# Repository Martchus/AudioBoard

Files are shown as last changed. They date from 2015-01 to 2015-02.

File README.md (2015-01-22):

# AudioBoard

Im Ordner Hardware befindet sich der Schaltplan als KiCAD Projekt und die Gerberdaten der Platine.

Die Software gibt es als "Basic" Version, welche die Grundlegenden Funktionen zur verfügung stellt. Auf der Basis von diesen Daten können eigene Projekte entwickelt werden.
Der Quelltext zum Matrixprojekt ist auf genau dieses Projekt zugeschnitten. Es wird dazu eine 7x6 Matrix mit WS2812 LEDs erwartete, welche alle seriell verbunden sind. Dieser Quelltext soll eher als Inspiration dienen.

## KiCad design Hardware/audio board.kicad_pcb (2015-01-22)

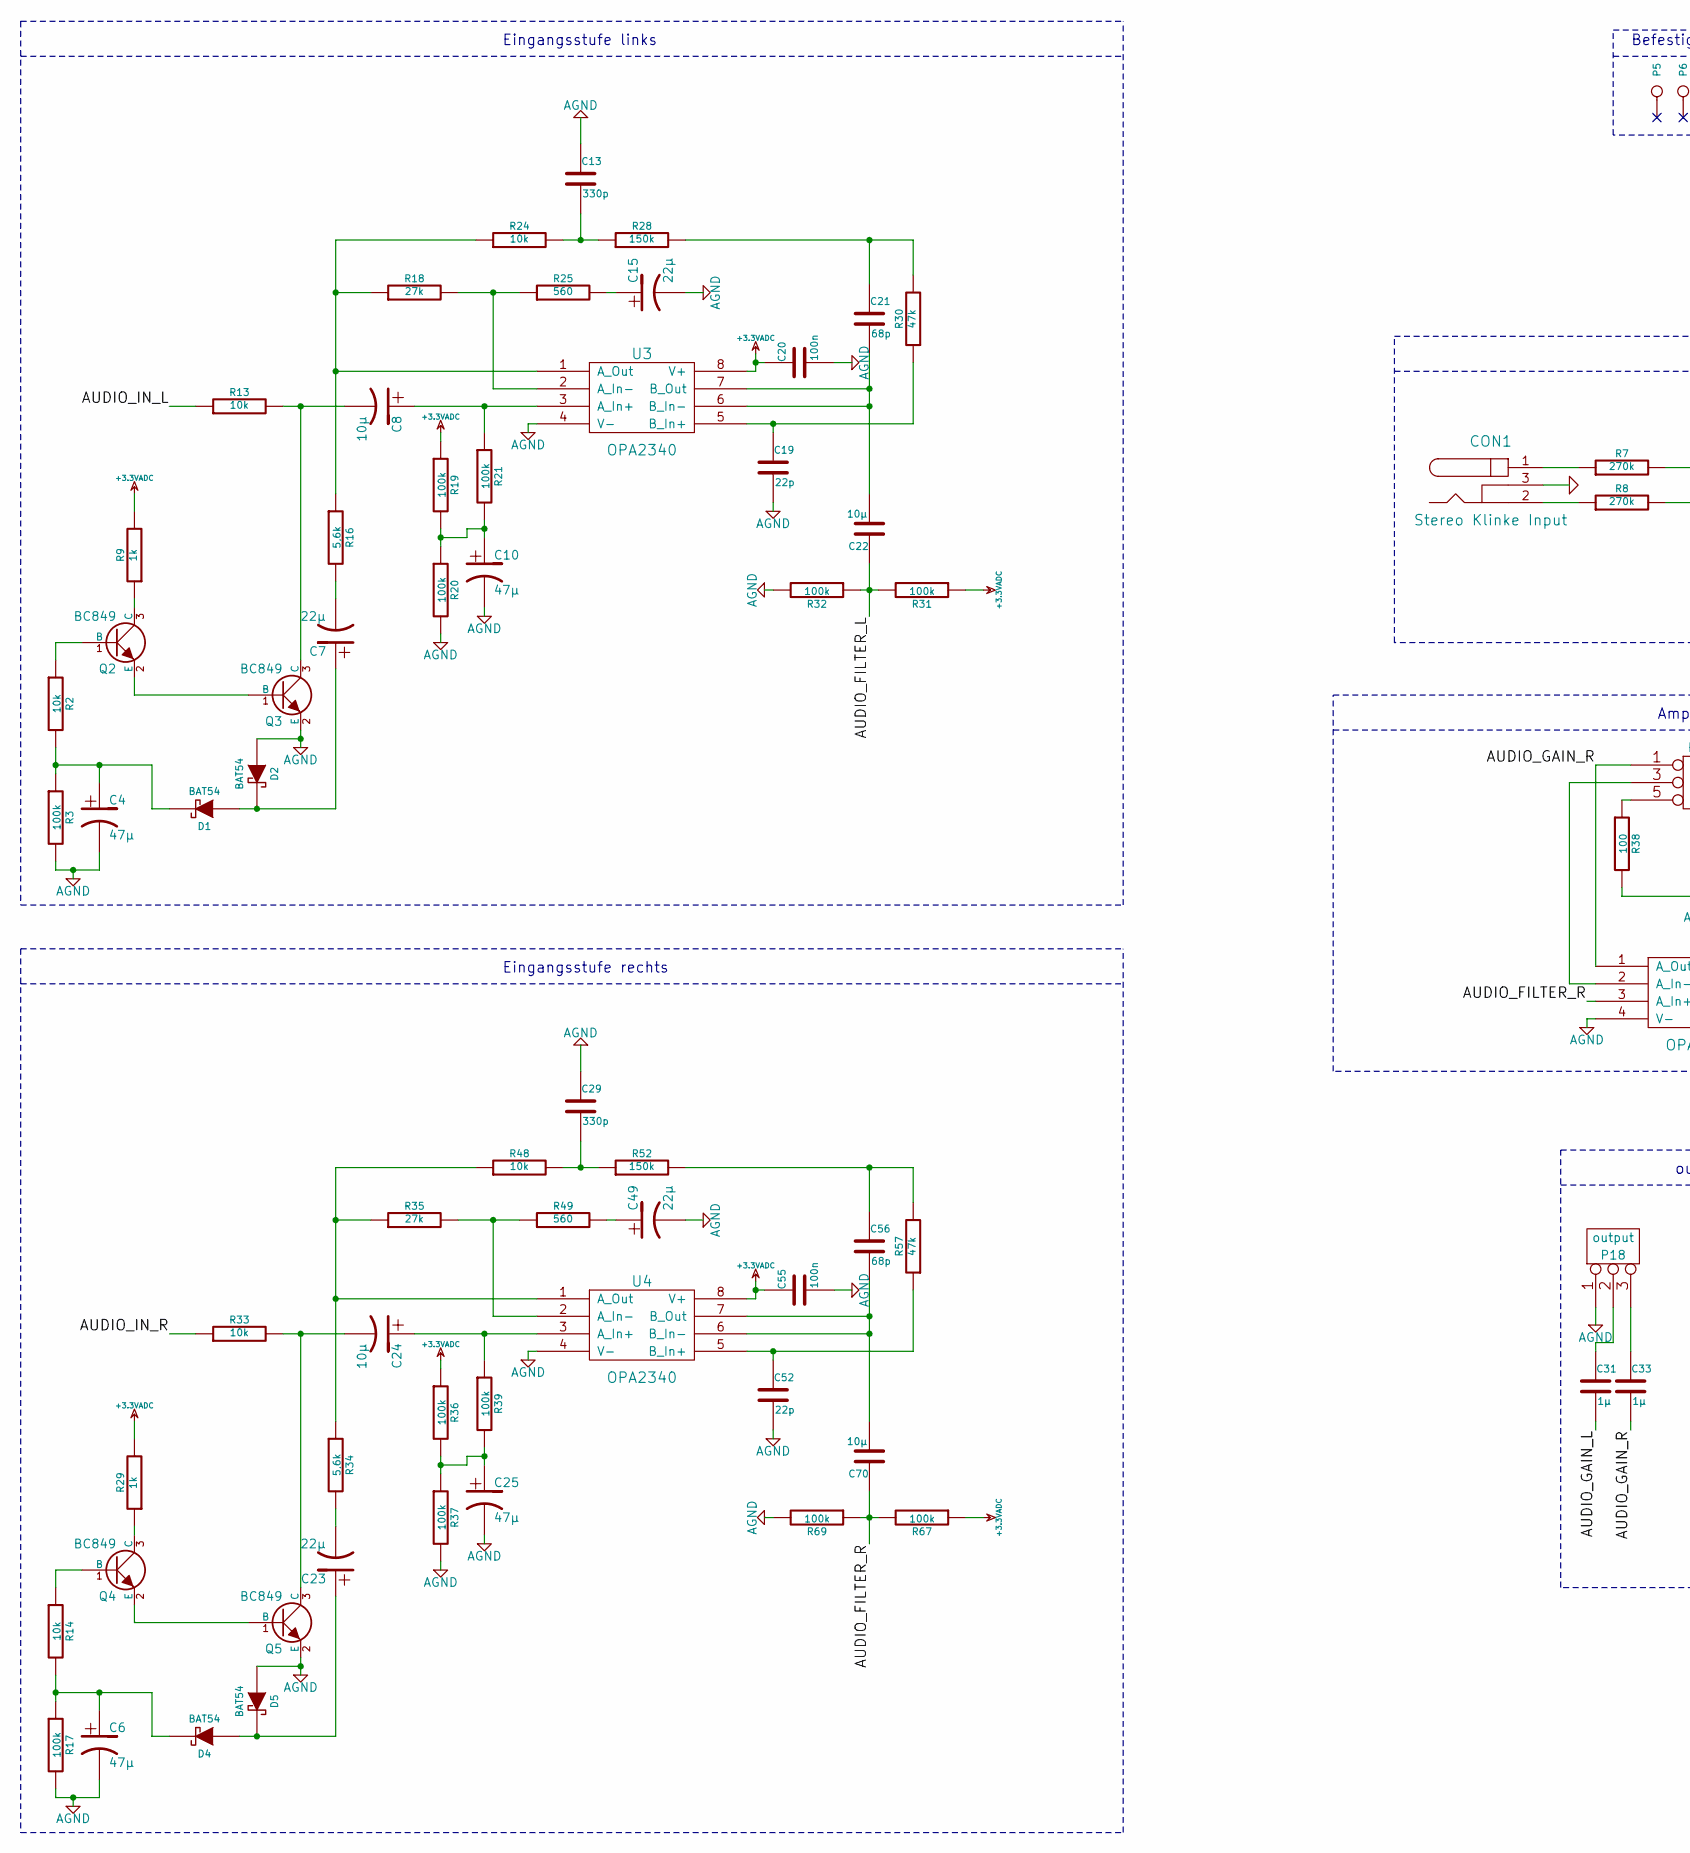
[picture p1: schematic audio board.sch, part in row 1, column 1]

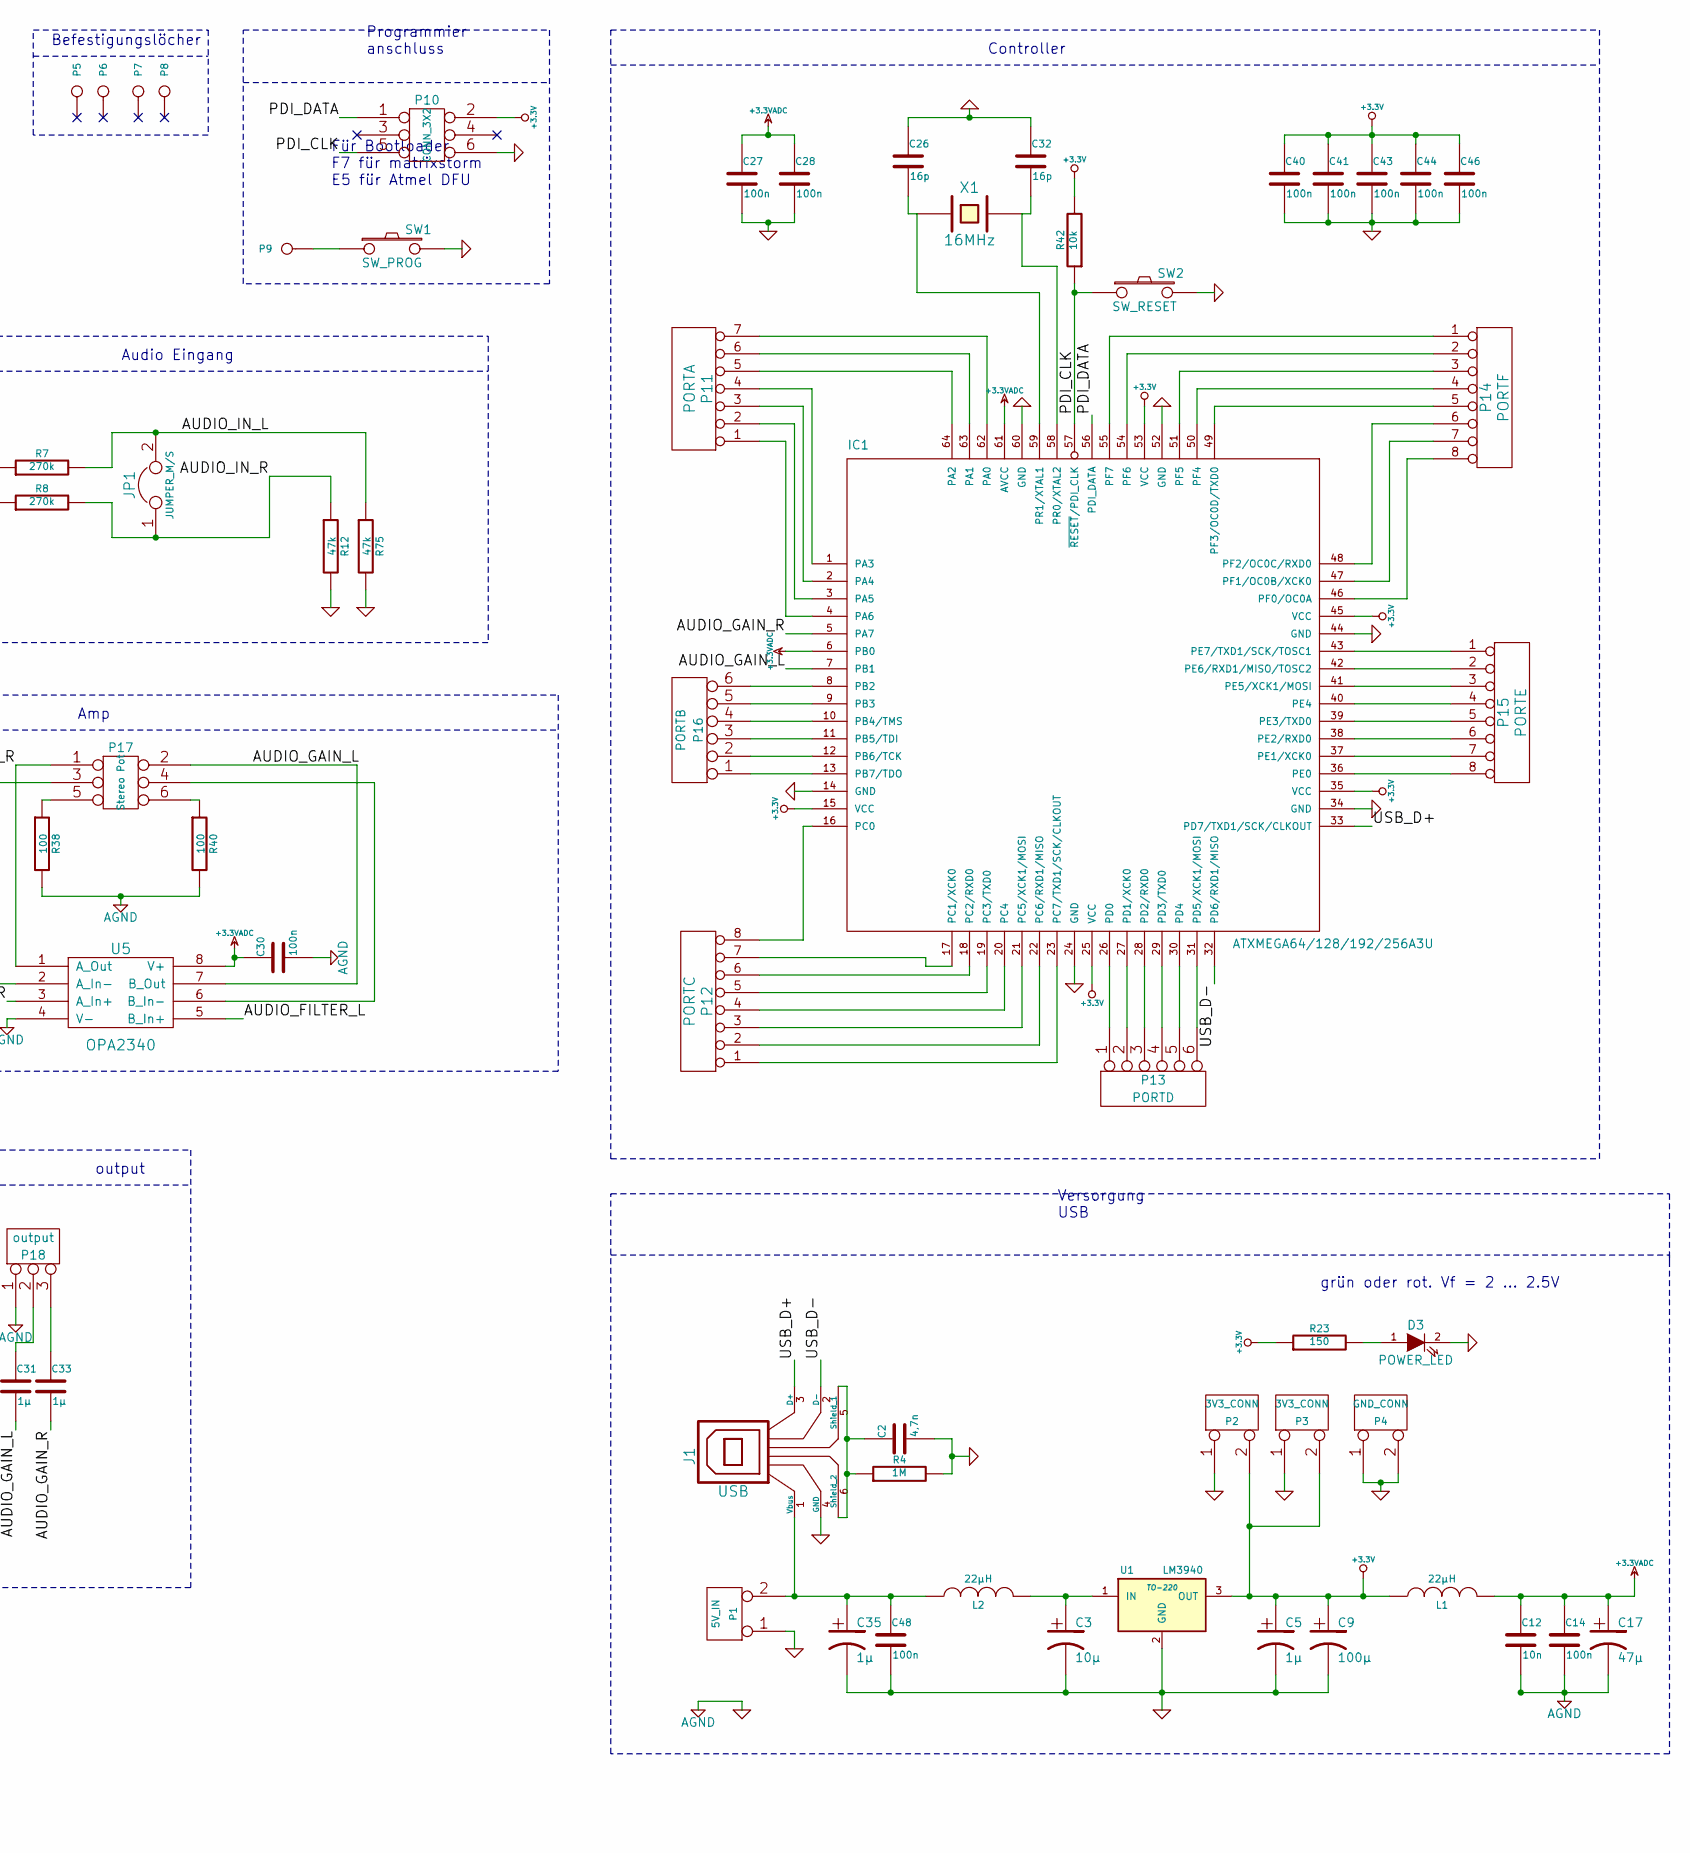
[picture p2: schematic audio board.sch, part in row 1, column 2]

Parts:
C2: 4,7n
C3, C8, C22, C24, C70: 10µ
C4, C6, C10, C17, C25: 47µ
C5, C31, C33, C35: 1µ
C7, C15, C23, C49: 22µ
C9: 100µ
C12: 10n
C13, C29: 330p
C14, C20, C27, C28, C30, C40, C41, C43, C44, C46, C48, C55: 100n
C19, C52: 22p
C21, C56: 68p
C26, C32: 16p
CON1: Stereo Klinke Input
D1, D2, D4, D5: BAT54
D3: POWER_LED
IC1: ATXMEGA64/128/192/256A3U; TQFP64
J1: USB
JP1: JUMPER_M/S
L1, L2: 22µH
P1: 5V_IN
P2, P3: 3V3_CONN
P4: GND_CONN
P5, P6, P7, P8: Bohrung
P9: CONN_1
P10: CONN_3X2
P11: PORTA
P12: PORTC
P13: PORTD
P14: PORTF
P15: PORTE
P16: PORTB
P17: Stereo Pot
P18: output
Q2, Q3, Q4, Q5: BC849
R2, R13, R14, R24, R33, R42, R48: 10k
R3, R17, R19, R20, R21, R31, R32, R36, R37, R39, R67, R69: 100k
R4: 1M
R7, R8: 270k
R9, R29: 1k
R12, R30, R57, R75: 47k
R16, R34: 5,6k
R18, R35: 27k
R23: 150
R25, R49: 560
R28, R52: 150k
R38, R40: 100
SW1: SW_PROG
SW2: SW_RESET
U1: LM3940; TO-220
U3, U4, U5: OPA2340
X1: 16MHz

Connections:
+3.3V: C5.1, C9.1, C40.1, C41.1, C43.1, C44.1, C46.1, IC1.15 (VCC), IC1.25 (VCC), IC1.35 (VCC), IC1.45 (VCC), IC1.53 (VCC), L1.1, P2.2 (PM), P3.2 (PM), P10.2, R23.1, R42.2, U1.3 (OUT)
+3.3VADC: C12.1, C14.1, C17.1, C20.1, C27.1, C28.1, C30.1, C55.1, IC1.6 (PB0), IC1.61 (AVCC), L1.2, R9.2, R19.1, R29.2, R31.1, R36.1, R67.1, U3.8 (V+), U4.8 (V+), U5.8 (V+)
/AUDIO_FILTER_L: C22.1, R31.2, R32.1, U5.5 (B_In+)
/AUDIO_FILTER_R: C70.1, R67.2, R69.1, U5.3 (A_In+)
/AUDIO_GAIN_L: C31.2, IC1.7 (PB1), P17.2, U5.7 (B_Out)
/AUDIO_GAIN_R: C33.2, IC1.5 (PA7), P17.1, U5.1 (A_Out)
/AUDIO_IN_L: JP1.2, R7.2, R13.1, R75.1
/AUDIO_IN_R: JP1.1, R8.2, R12.1, R33.1
/PDI_CLK: IC1.57 (~RESET~/PDI_CLK), P10.5, R42.1, SW2.1
/PDI_DATA: IC1.56 (PDI_DATA), P10.1
/USB_D+: IC1.33 (PD7/TXD1/SCK/CLKOUT), J1.3 (D+)
/USB_D-: IC1.32 (PD6/RXD1/MISO), J1.2 (D-)
AGND: C2.2, C3.2, C4.2, C5.2, C6.2, C9.2, C10.2, C12.2, C13.1, C14.2, C15.2, C17.2, C19.2, C20.2, C25.2, C26.1, C27.2, C28.2, C29.1, C30.2, C32.1, C35.2, C40.2, C41.2, C43.2, C44.2, C46.2, C48.2, C49.2, C52.2, C55.2, CON1.3, D2.1 (A), D3.2 (K), D5.1 (A), IC1.14 (GND), IC1.24 (GND), IC1.34 (GND), IC1.44 (GND), IC1.52 (GND), IC1.60 (GND), J1.4 (GND), P1.1, P2.1, P3.1, P4.1, P4.2 (PM), P10.6, P18.1, Q3.2 (E), Q5.2 (E), R3.2, R4.2, R12.2, R17.2, R20.2, R32.2, R37.2, R38.2, R40.2, R69.2, R75.2, SW1.2, SW2.2, U1.2 (GND), U3.4 (V-), U4.4 (V-), U5.4 (V-)
unnamed: IC1.46 (PF0/OC0A), P14.8
unnamed: IC1.54 (PF6), P14.2
unnamed: IC1.51 (PF5), P14.3
unnamed: IC1.50 (PF4), P14.4
unnamed: IC1.49 (PF3/OC0D/TXD0), P14.5
unnamed: IC1.48 (PF2/OC0C/RXD0), P14.6
unnamed: IC1.47 (PF1/OC0B/XCK0), P14.7
unnamed: IC1.55 (PF7), P14.1
unnamed: P9.1, SW1.1
unnamed: IC1.43 (PE7/TXD1/SCK/TOSC1), P15.1
unnamed: IC1.42 (PE6/RXD1/MISO/TOSC2), P15.2
unnamed: IC1.40 (PE4), P15.4
unnamed: IC1.39 (PE3/TXD0), P15.5
unnamed: IC1.38 (PE2/RXD0), P15.6
unnamed: IC1.37 (PE1/XCK0), P15.7
unnamed: IC1.36 (PE0), P15.8
unnamed: IC1.64 (PA2), P11.5
unnamed: IC1.62 (PA0), P11.7
unnamed: IC1.63 (PA1), P11.6
unnamed: IC1.1 (PA3), P11.4
unnamed: IC1.2 (PA4), P11.3
unnamed: IC1.3 (PA5), P11.2
unnamed: IC1.4 (PA6), P11.1
unnamed: IC1.11 (PB5/TDI), P16.3
unnamed: C10.1, R19.2, R20.1, R21.2
unnamed: C8.2, Q3.3 (C), R13.2
unnamed: Q2.2 (E), Q3.1 (B)
unnamed: Q2.3 (C), R9.1
unnamed: C4.1, D1.3 (K), R2.2, R3.1
unnamed: Q2.1 (B), R2.1
unnamed: C7.2, R16.2
unnamed: C15.1, R25.2
unnamed: R18.2, R25.1, U3.2 (A_In-)
unnamed: C8.1, R21.1, U3.3 (A_In+)
unnamed: CON1.1, R7.1
unnamed: CON1.2, R8.1
unnamed: IC1.9 (PB3), P16.5
unnamed: IC1.8 (PB2), P16.6
unnamed: IC1.41 (PE5/XCK1/MOSI), P15.3
unnamed: IC1.12 (PB6/TCK), P16.2
unnamed: IC1.10 (PB4/TMS), P16.4
unnamed: P17.3, U5.2 (A_In-)
unnamed: C2.1, J1.5 (Shield_1), J1.6 (Shield_2), R4.1
unnamed: C3.1, L2.2, U1.1 (IN)
unnamed: D3.1 (A), R23.2
unnamed: C56.2, C70.2, U4.6 (B_In-), U4.7 (B_Out)
unnamed: IC1.16 (PC0), P12.8
unnamed: IC1.13 (PB7/TDO), P16.1
unnamed: C23.2, R34.2
unnamed: C6.1, D4.3 (K), R14.2, R17.1
unnamed: R34.1, R35.1, R48.1, U4.1 (A_Out)
unnamed: R35.2, R49.1, U4.2 (A_In-)
unnamed: C29.2, R48.2, R52.1
unnamed: C56.1, R52.2, R57.2
unnamed: C52.1, R57.1, U4.5 (B_In+)
unnamed: P17.4, U5.6 (B_In-)
unnamed: P17.6, R40.1
unnamed: P17.5, R38.1
unnamed: C31.1, P18.2 (PM)
unnamed: C33.1, P18.3
unnamed: IC1.27 (PD1/XCK0), P13.2
unnamed: IC1.20 (PC4), P12.4
unnamed: IC1.21 (PC5/XCK1/MOSI), P12.3
unnamed: IC1.22 (PC6/RXD1/MISO), P12.2
unnamed: IC1.23 (PC7/TXD1/SCK/CLKOUT), P12.1
unnamed: IC1.31 (PD5/XCK1/MOSI), P13.6
unnamed: IC1.19 (PC3/TXD0), P12.5
unnamed: IC1.26 (PD0), P13.1
unnamed: IC1.30 (PD4), P13.5
unnamed: IC1.29 (PD3/TXD0), P13.4
unnamed: IC1.28 (PD2/RXD0), P13.3
unnamed: C26.2, IC1.59 (PR1/XTAL1), X1.1
unnamed: C32.2, IC1.58 (PR0/XTAL2), X1.2
unnamed: C21.1, R28.2, R30.2
unnamed: R16.1, R18.1, R24.1, U3.1 (A_Out)
unnamed: C13.2, R24.2, R28.1
unnamed: C21.2, C22.2, U3.6 (B_In-), U3.7 (B_Out)
unnamed: C19.1, R30.1, U3.5 (B_In+)
unnamed: IC1.18 (PC2/RXD0), P12.6
unnamed: Q4.2 (E), Q5.1 (B)
unnamed: C24.1, R39.1, U4.3 (A_In+)
unnamed: C25.1, R36.2, R37.1, R39.2
unnamed: C24.2, Q5.3 (C), R33.2
unnamed: Q4.3 (C), R29.1
unnamed: Q4.1 (B), R14.1
unnamed: IC1.17 (PC1/XCK0), P12.7
unnamed: C35.1, C48.1, J1.1 (Vbus), L2.1, P1.2 (PM)
unnamed: C49.1, R49.2
unnamed: C7.1, D1.1 (A), D2.3 (K)
unnamed: C23.1, D4.1 (A), D5.3 (K)

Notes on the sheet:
Controller
Programmier anschluss
Versorgung USB
grün oder rot. Vf = 2 ... 2.5V
Für Bootloader F7 für matrixstorm E5 für Atmel DFU
Eingangsstufe links
Befestigungslöcher
Eingangsstufe rechts
Audio Eingang
Amp
output

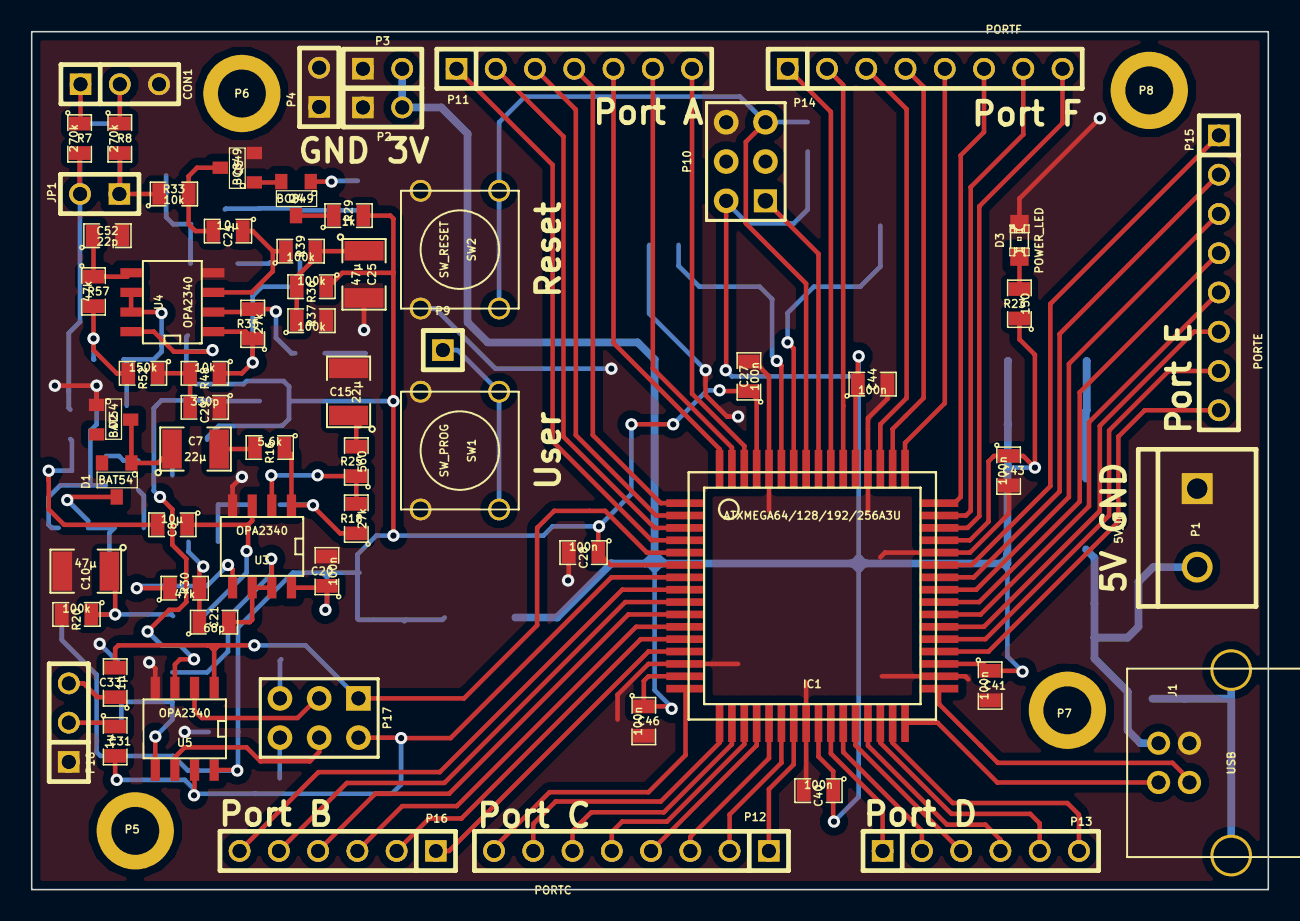
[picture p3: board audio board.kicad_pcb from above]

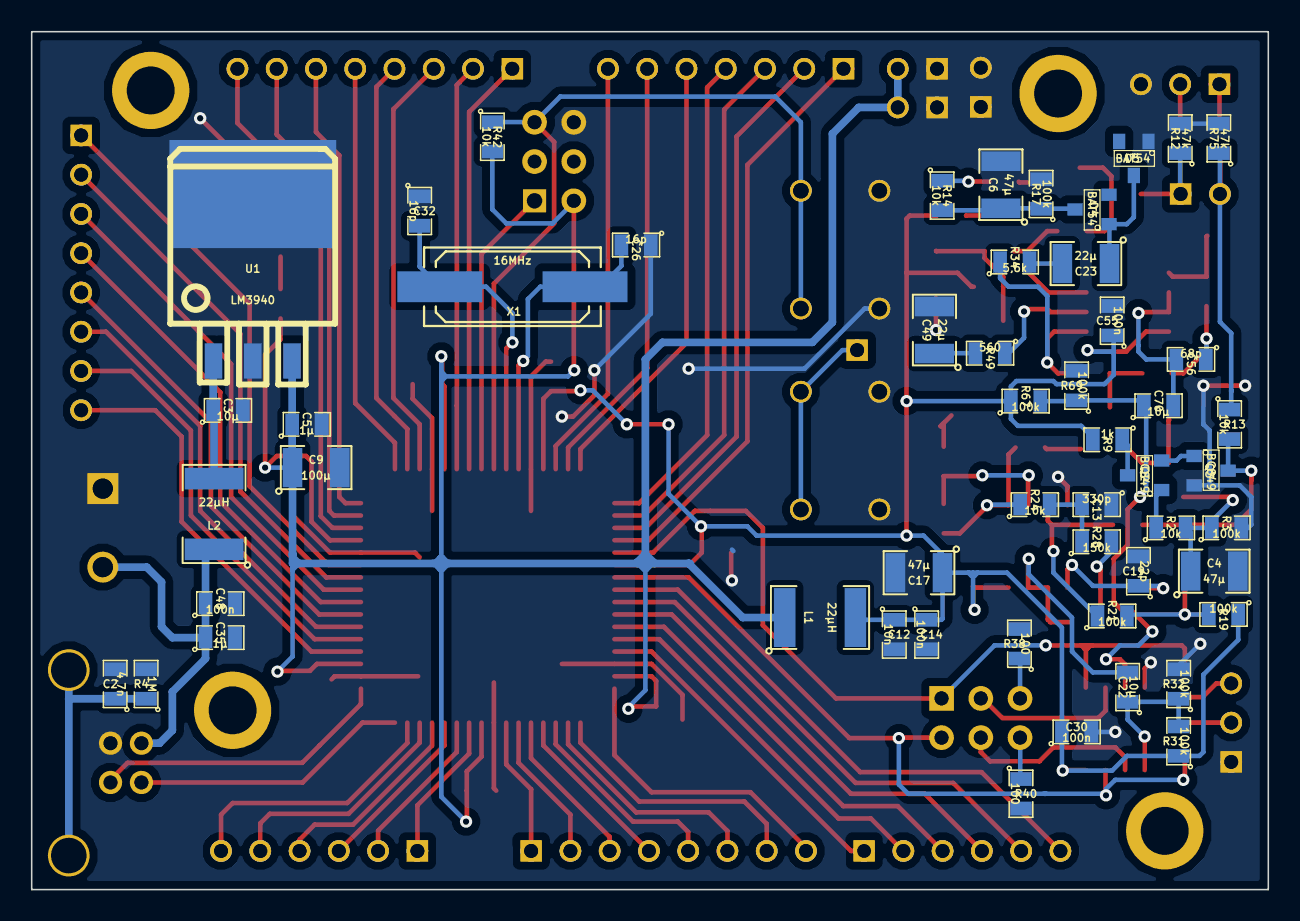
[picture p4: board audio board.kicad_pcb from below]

Board: 2 copper layers, 80.0 x 55.5 mm, 120 parts (52 on the bottom side), 103 nets.

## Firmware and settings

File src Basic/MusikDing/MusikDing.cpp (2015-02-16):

/*
this is the main file. you should only modify this at the marked locations

used peripherals for all basic modules:
TCC1 - systemt imer
TCC0 - sampling timer

TWIE - LCD

USARTC1 - LED

DMA0 - LED
DMA1 - ADC
DMA2 - ADC

ADCA
ADCB
 */ 

#include <avr/io.h>
#include <util/delay.h>
#include <avr/interrupt.h>
#include <stdlib.h>

#include "global.h"
#include "adc.h"
#include "CFFT.h"
#include "animation.h"

CFFT fft;

volatile uint32_t systick;			// system time [ms]

#define FLAG_FRAME		0x01
#define FLAG_100HZ		0x02
#define FLAG_DOSAMPLE	0x04
#define FLAG_FFTDONE	0x08
volatile uint8_t flags, adc_state;

// generate seed for RNG
unsigned short get_seed() {
	unsigned short seed = 0;
	unsigned short *p = (unsigned short*)(RAMEND + 1);
	extern unsigned short __heap_start;
	
	while(p >= &__heap_start + 1)
		seed ^= *(--p);
	
	return seed;
}

int main(void)
{
	// use external clock and activate PLL
	OSC.XOSCCTRL = OSC_FRQRANGE_12TO16_gc | OSC_XOSCSEL_XTAL_16KCLK_gc;
	OSC.CTRL |= OSC_XOSCEN_bm;
	while(!(OSC.STATUS & OSC_XOSCRDY_bm))
		;
	OSC.PLLCTRL = OSC_PLLSRC_XOSC_gc | 2;
	OSC.CTRL |= OSC_PLLEN_bm;
	while(!(OSC.STATUS & OSC_PLLRDY_bm))
		;
	CCP = CCP_IOREG_gc;
	CLK.CTRL = CLK_SCLKSEL_PLL_gc;
	OSC.CTRL &= ~OSC_RC2MEN_bm;
	
	// system timer every ms
	systick = 0;
	TCC1.CTRLA = TC_CLKSEL_DIV1_gc;
	TCC1.INTCTRLA = TC_OVFINTLVL_MED_gc;
	TCC1.PER = 31999;
	
	DMA.CTRL = DMA_ENABLE_bm;
	
	_delay_ms(100);
	
	anim_init();
	adc_init();
	srand(get_seed());
	
	flags = 0;
	adc_state = ADC_STATE_IDLE;
	
	PMIC.CTRL |= (PMIC_LOLVLEN_bm | PMIC_MEDLVLEN_bm | PMIC_HILVLEN_bm);
	sei();
	
    while(1)
    {	
		// check sampling
		if(adc_state == ADC_STATE_SAMPLING)
		{
			adc_check();
		}
		
		// every 10 ms
		if(flags & FLAG_100HZ)
		{		
			// TODO: important tasks, which needs to be checked every 10ms e.g. poll inputs
			
			flags &= ~FLAG_100HZ;
		}
		
		// calculate new frame
		else if(flags & FLAG_FRAME)
		{
			// TODO: change this function in animtion.cpp so it calculates the next frame and sends it to an output
			anim_frame();

			flags &= ~FLAG_FRAME;
		}
		
		// sample new data
		else if((adc_state == ADC_STATE_IDLE) && (flags & FLAG_DOSAMPLE))
		{
			adc_startSampling();
			
			flags &= ~FLAG_DOSAMPLE;
		}
		
		// start calculations
		else if(adc_state == ADC_STATE_SAMPLING_DONE)
		{	
			fft.doFFT();
			adc_state = ADC_STATE_WAIT;
		}
		
		 // processing data
		 else if(adc_state == ADC_STATE_WAIT)
		 {
			if(!fft.doStep())
			{
				flags |= FLAG_FFTDONE;
				adc_state = ADC_STATE_IDLE;
			}
		 }
		 
		 // fft done. put data into animation system
		 else if(flags & FLAG_FFTDONE)
		 {
			anim_inputData(fft.getLeft(), fft.getRight()); 
			flags &= ~FLAG_FFTDONE;
		 }
		
		// if nothing else to do
		else
		{
			// TODO: here you can add unimportant tasks like sending data to a display
		}
    }
}

#define TIME_FRAME		16 //33
#define TIME_100HZ		10
#define TIME_SAMPLE		50

ISR(TCC1_OVF_vect)
{
	static uint8_t cnt_frame = TIME_FRAME, cnt_100hz = TIME_100HZ;
	static uint16_t cnt_capture = TIME_SAMPLE;
	
	cnt_frame--;
	if(!cnt_frame)
	{
		PORTF.OUTTGL = PIN0_bm;
		flags |= FLAG_FRAME;
		cnt_frame = TIME_FRAME;
	}
	
	cnt_100hz--;
	if(!cnt_100hz)
	{
		flags |= FLAG_100HZ;
		cnt_100hz = TIME_100HZ;
	}
	
	cnt_capture--;
	if(!cnt_capture)
	{
		flags |= FLAG_DOSAMPLE;
		cnt_capture = TIME_SAMPLE;
	}
	
	systick++;
}

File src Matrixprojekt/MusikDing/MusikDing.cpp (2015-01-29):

/*
TCC1 - System timer
TCC0 - Sampling

TWIE - LCD

USARTC1 - LED

DMA0 - LED
DMA1 - ADC
DMA2 - ADC

ADCA
ADCB
 */ 

#include <avr/io.h>
#include <util/delay.h>
#include <avr/interrupt.h>
#include <stdlib.h>

#include "CSSD1306.h"
#include "CInput.h"
#include "CLED.h"
#include "global.h"
#include "adc.h"
#include "CFFT.h"
#include "animation.h"

CSSD1306 lcd;
CInput input;
CLED led;
CFFT fft;

volatile uint32_t systick;

#define FLAG_FRAME		0x01
#define FLAG_100HZ		0x02
#define FLAG_DOSAMPLE	0x04
#define FLAG_FFTDONE	0x08
volatile uint8_t flags, adc_state;

#ifdef __APS_DEBUG__
uint32_t aps_tick = 0;
uint8_t _fps = 0, _sps = 0, __fps = 0, __sps = 0;
#endif

// seed für zufallsgenerator erzeugen
unsigned short get_seed() {
	unsigned short seed = 0;
	unsigned short *p = (unsigned short*)(RAMEND + 1);
	extern unsigned short __heap_start;
	
	while(p >= &__heap_start + 1)
		seed ^= *(--p);
	
	return seed;
}

int main(void)
{
	// auf ext. Clock umstellen und PLL aktivieren
	OSC.XOSCCTRL = OSC_FRQRANGE_12TO16_gc | OSC_XOSCSEL_XTAL_16KCLK_gc;
	OSC.CTRL |= OSC_XOSCEN_bm;
	while(!(OSC.STATUS & OSC_XOSCRDY_bm))
		;
	OSC.PLLCTRL = OSC_PLLSRC_XOSC_gc | 2;
	OSC.CTRL |= OSC_PLLEN_bm;
	while(!(OSC.STATUS & OSC_PLLRDY_bm))
		;
	CCP = CCP_IOREG_gc;
	CLK.CTRL = CLK_SCLKSEL_PLL_gc;
	OSC.CTRL &= ~OSC_RC2MEN_bm;

	// interne 32MHz
// 	OSC.CTRL |= OSC_RC32MEN_bm;
// 	while(!(OSC.STATUS & OSC_RC32MRDY_bm))
// 		;
// 	CCP = CCP_IOREG_gc;
// 	CLK.CTRL = CLK_SCLKSEL_RC32M_gc;
// 	OSC.CTRL &= ~OSC_RC2MEN_bm;
	
	// Systemtimer	alle 1 ms
	systick = 0;
	TCC1.CTRLA = TC_CLKSEL_DIV1_gc;
	TCC1.INTCTRLA = TC_OVFINTLVL_MED_gc;
	TCC1.PER = 31999;
	
	DMA.CTRL = DMA_ENABLE_bm;
	
	_delay_ms(100);
	lcd.init();
	
	anim_init();
	adc_init();
	srand(get_seed());
	
	flags = 0;
	adc_state = ADC_STATE_IDLE;
	
	PMIC.CTRL |= (PMIC_LOLVLEN_bm | PMIC_MEDLVLEN_bm | PMIC_HILVLEN_bm);
	sei();

	anim_start(6);
	anim_setDelay(30000);
//	anim_setFlags(ANIM_FLAG_RANDOM | ANIM_FLAG_CHANGE | ANIM_FLAG_NOREPEAT);
	
    while(1)
    {	
		input.pollEnc();
		
		// sampling läuft
		if(adc_state == ADC_STATE_SAMPLING)
		{
			adc_check();
		}
		
		// alle 10 ms
		if(flags & FLAG_100HZ)
		{		
			input.pollBtn();		
			
			// !!!
			
			flags &= ~FLAG_100HZ;
		}
		
		// neues bild berechnen
		else if(flags & FLAG_FRAME && !led.isBusy())
		{
#ifdef __APS_DEBUG__
			_fps++;
#endif
			anim_frame();

			flags &= ~FLAG_FRAME;
		}
		
		// neue Daten einlesen
		else if((adc_state == ADC_STATE_IDLE) && (flags & FLAG_DOSAMPLE))
		{
			adc_startSampling();
			
			flags &= ~FLAG_DOSAMPLE;
		}
		
		// auswerten starten
		else if(adc_state == ADC_STATE_SAMPLING_DONE)
		{	
			fft.doFFT();
			adc_state = ADC_STATE_WAIT;
		}
		
		 // auswerten
		 else if(adc_state == ADC_STATE_WAIT)
		 {
			if(!fft.doStep())
			{
				flags |= FLAG_FFTDONE;
				adc_state = ADC_STATE_IDLE;
			}
		 }
		 
		 // fft fertig -> was damit machen
		 else if(flags & FLAG_FFTDONE)
		 {
#ifdef __APS_DEBUG__
			_sps++;
#endif
			anim_inputData(fft.getLeft(), fft.getRight()); 
			flags &= ~FLAG_FFTDONE;
		 }
		
		// sonst anderen kram
		else
		{
			lcd.update();		
		}
		
#ifdef __APS_DEBUG__
		if(systick >= aps_tick)
		{
			aps_tick = systick + 1000;
			
			__fps = _fps;
			__sps = _sps;
			
			_fps = 0;
			_sps = 0;
		}
#endif
    }
}

#define TIME_FRAME		16 //33
#define TIME_100HZ		10
#define TIME_SAMPLE		50

ISR(TCC1_OVF_vect)
{
	static uint8_t cnt_frame = TIME_FRAME, cnt_100hz = TIME_100HZ;
	static uint16_t cnt_capture = TIME_SAMPLE;
	
	cnt_frame--;
	if(!cnt_frame)
	{
		PORTF.OUTTGL = PIN0_bm;
		flags |= FLAG_FRAME;
		cnt_frame = TIME_FRAME;
	}
	
	cnt_100hz--;
	if(!cnt_100hz)
	{
		flags |= FLAG_100HZ;
		cnt_100hz = TIME_100HZ;
	}
	
	cnt_capture--;
	if(!cnt_capture)
	{
		flags |= FLAG_DOSAMPLE;
		cnt_capture = TIME_SAMPLE;
	}
	
	systick++;
}
